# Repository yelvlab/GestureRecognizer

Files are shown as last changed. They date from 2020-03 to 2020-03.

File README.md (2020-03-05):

# GestureRecognizer
Arduino gesture recognizer 

**Arduino Micro & APDS-9960**

# 项目进展预览：

- 测试版v0.1

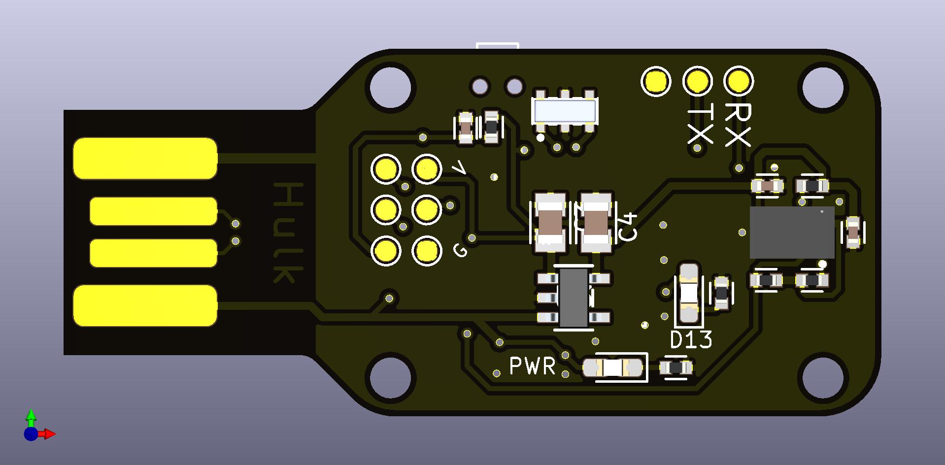
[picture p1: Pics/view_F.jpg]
Fornt


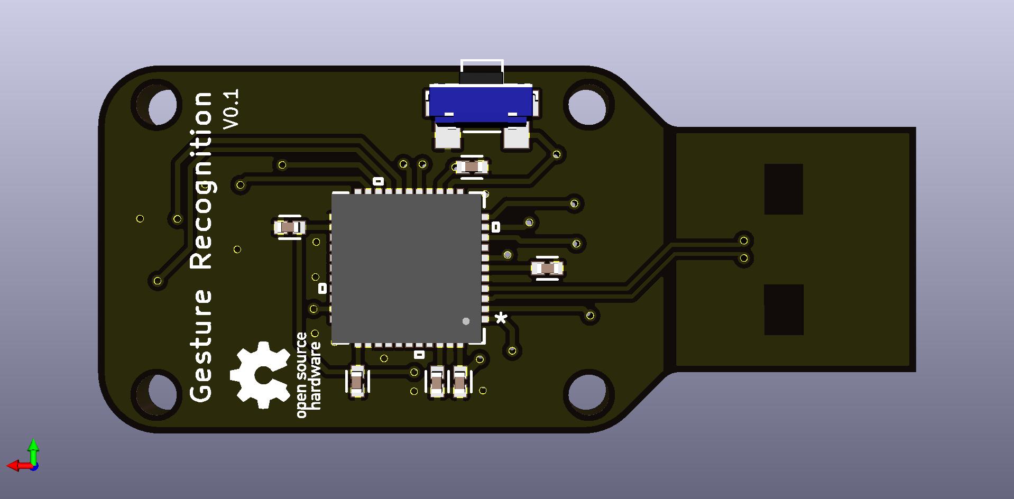
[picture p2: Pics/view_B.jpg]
Bottom


# 项目介绍：

- 灵感来源：[项目分享| 仅79行代码完成创意无限的手势识别-达尔闻](https://mp.weixin.qq.com/s/ycUFOZZUidfz-ktJOUYYWw)

- 驱动库：[SparkFun APDS-9960](https://github.com/sparkfun/SparkFun_APDS-9960_Sensor_Arduino_Library)

# 文件介绍：

## CADs 目录:

- `keep_out.dwg`

PCB 边框切割以及螺丝孔文件

- `acrylic_cut.dwg`

亚克力外壳切割文件

## PCB工程目录：

- `GestureRecongnition_vx.x`目录

开源PCB工具`KiCAD`项目工程文件，`vx.x`为版本号

`v0.x`为测试版本

## Docs目录：

- `APDS9960.pdf`

`APDS-9960`模组数据手册

- `arduino_micro_schematic.pdf`

Arduino Micro 开发板原理图文件

- `atmel-atmega16u4-32u4_datasheet.pdf`

ATMEL公司`ATMEGA32U4`芯片数据手册

- `SPX3819-3.3.pdf`

`SPX3819` LDO指定输出3.3V芯片手册

## Pics目录：

- `view_F.jpg`:

PCB 3D预览顶视图

- `view_B.jpg`:

PCB 3D预览底视图

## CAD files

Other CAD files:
CADs/acrylic_cut.dwg
CADs/keep_out.dwg

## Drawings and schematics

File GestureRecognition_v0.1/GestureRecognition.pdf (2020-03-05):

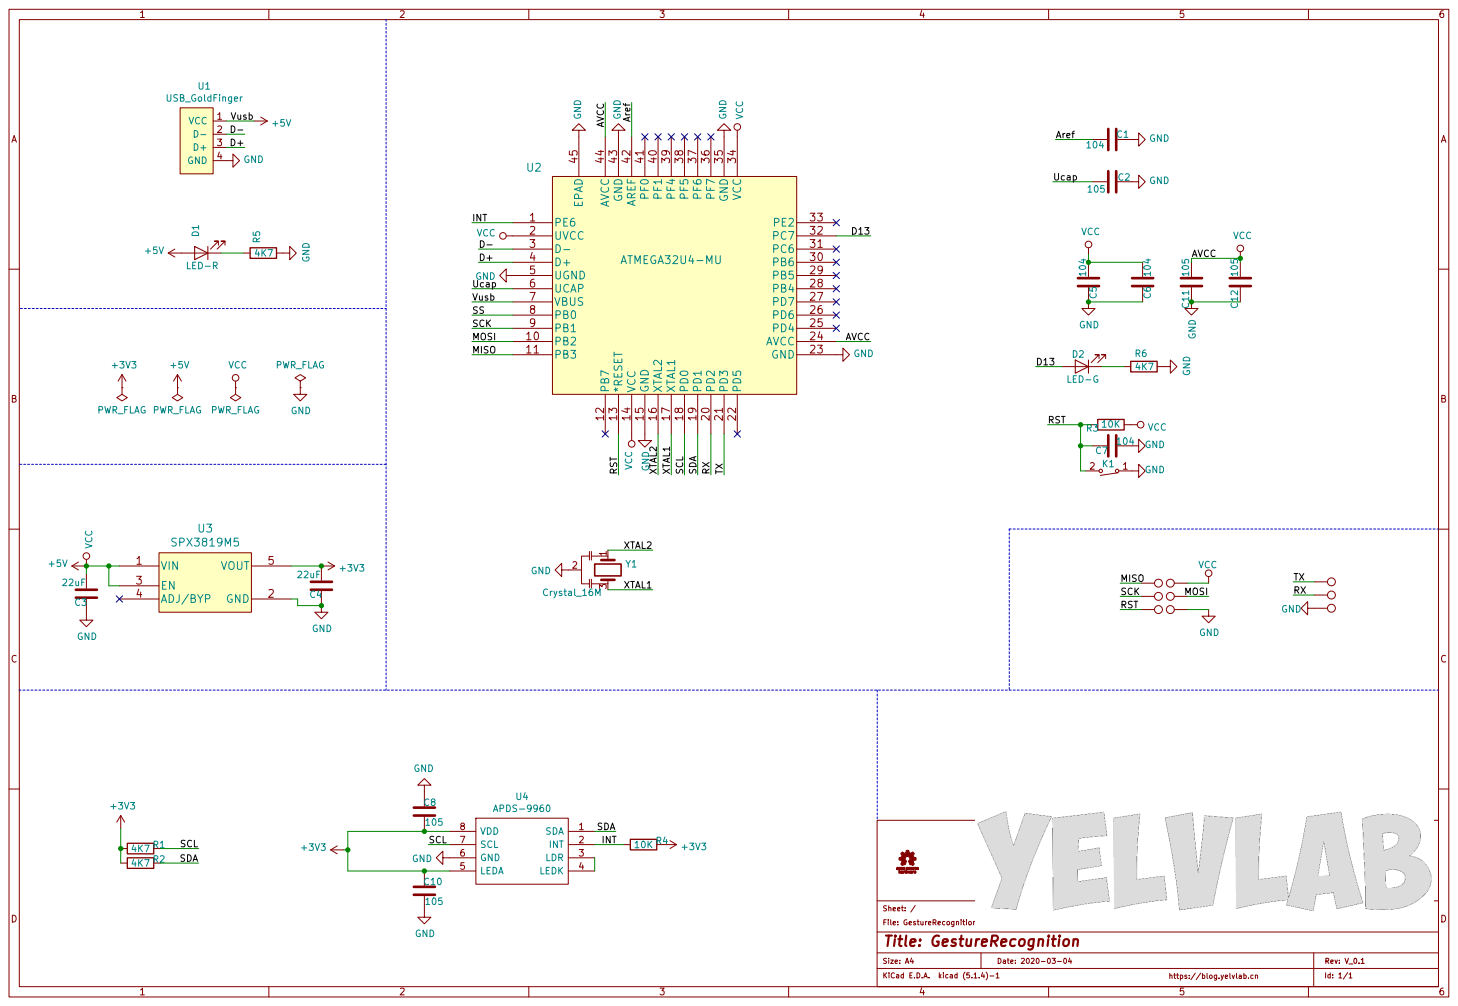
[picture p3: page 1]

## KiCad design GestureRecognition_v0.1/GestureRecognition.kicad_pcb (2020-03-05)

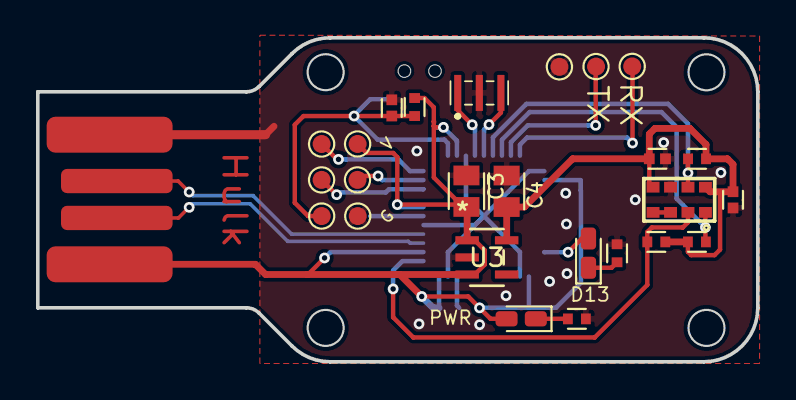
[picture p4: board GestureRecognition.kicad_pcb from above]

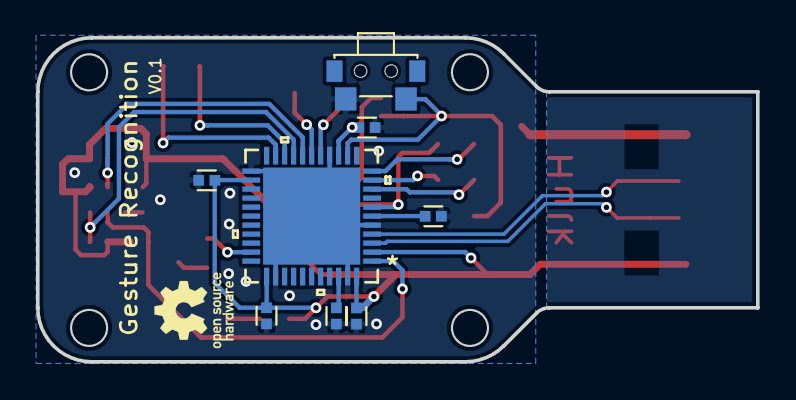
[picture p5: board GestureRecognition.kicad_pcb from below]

Board: 2 copper layers, 40.0 x 18.0 mm, 34 parts (8 on the bottom side), 22 nets.

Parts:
C1, C5, C6, C7: 104; C0402
C2, C8, C10, C11, C12: 105; C0402
C3, C4: 22uF; C0805
D1: LED-R; LED_0603_1608Metric_Castellated
D2: LED-G; LED_0603_1608Metric_Castellated
K1: TS-018_TS24CA
R1, R2, R5, R6: 4K7; R0402
R3, R4: 10K; R0402
TP1, TP2, TP3, TP4, TP5, TP6, TP7, TP8, TP9: TestPoint; TestPoint_Pad_D1.0mm
U1: USB_GoldFinger; USB-kingfigure
U2: ATMEGA32U4-MU
U3: SPX3819M5; SPX3819M5-L-3-3&slash_TR
U4: APDS-9960; APDS-9950
Y1: Crystal_16M; CSTCE16M

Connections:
+3V3: C4.2, C8.2, C10.1, R1.2, R2.2, R4.1, U3.5, U4.5, U4.8
+5V: C3.2, C5.2, C6.2, C11.2, C12.2, D1.2, R3.2, TP5.1, U1.1, U2.2, U2.7, U2.14, U2.24, U2.34, U2.44, U3.1, U3.3
/Aref: C1.2, U2.42
/D13: D2.2, U2.32
/D+: U1.3, U2.4
/D-: U1.2, U2.3
/INT: R4.2, U2.1, U4.2
/MISO: TP4.1, U2.11
/MOSI: TP7.1, U2.10
/RST: C7.1, K1.2, R3.1, TP8.1, U2.13
/RX: TP2.1, U2.20
/SCK: TP6.1, U2.9
/SCL: R1.1, U2.18, U4.7
/SDA: R2.1, U2.19, U4.1
/TX: TP3.1, U2.21
/Ucap: C2.1, U2.6
/XTAL1: U2.17, Y1.3
/XTAL2: U2.16, Y1.1
GND: C1.1, C2.2, C3.1, C4.1, C5.1, C6.1, C7.2, C8.1, C10.2, C11.1, C12.1, K1.1, R5.1, R6.1, TP1.1, TP9.1, U1.4, U2.5, U2.15, U2.23, U2.35, U2.43, U2.45, U3.2, U4.6, Y1.2
unnamed: D1.1, R5.2
unnamed: D2.1, R6.2
unnamed: U4.3, U4.4

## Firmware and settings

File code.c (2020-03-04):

#include <Keyboard.h>
#include <Mouse.h>
#include <SparkFun_APDS9960.h>

SparkFun_APDS9960 gestureSensor;
const unsigned short GESTURE_INT_PIN = 1;

volatile boolean hasMovement = false;

/**
   The main business logic. Translates gestures to keyboard events.
*/
void handleGesture() {
  if (gestureSensor.isGestureAvailable()) {
    switch (gestureSensor.readGesture()) {
      case DIR_UP:
        Keyboard.press(KEY_LEFT_ARROW);
        break;
      case DIR_DOWN:
        Keyboard.press(KEY_RIGHT_ARROW);
        break;
      case DIR_LEFT:
        Mouse.move(0, 0, -10);
        break;
      case DIR_RIGHT:
        Mouse.move(0, 0, 10);
        break;
      case DIR_NEAR:
        Keyboard.press(' ');
        break;
      case DIR_FAR:
        Keyboard.press(KEY_ESC);
        break;
      default:
        break;
    }
    Keyboard.releaseAll();
  }
}

/**
   Gets called whenever the gesture module signals there are new data to be sent
*/
void transmissionReady() {
  hasMovement = true;
}

/**
   Initializes gesture sensor
  @return whether gesture sensor initialization was successful
*/
boolean initializeGestureSensor() {
  return gestureSensor.init() && gestureSensor.enableGestureSensor(true);
}

void setup() {
  Keyboard.begin();
  Mouse.begin();
  attachInterrupt(digitalPinToInterrupt(GESTURE_INT_PIN), transmissionReady, FALLING);
  boolean initializationSuccessful = initializeGestureSensor();
  // If ADPS sensor failed to initialize, block and send error messages via Serial
  if (!initializationSuccessful) {
    Serial.begin(9600);
    while (!initializationSuccessful) {
      Serial.println("Error while initializing the gesture sensor");
      delay(10000);
    }
  }
}

void loop() {
  if (hasMovement) {
    handleGesture();
    hasMovement = false;
    // Reinitialize as workaround for sensor hanging when gesturing too fast
    initializeGestureSensor();
  }
}

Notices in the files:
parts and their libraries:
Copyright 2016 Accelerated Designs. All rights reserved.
